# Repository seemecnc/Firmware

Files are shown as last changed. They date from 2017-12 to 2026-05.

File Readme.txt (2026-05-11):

Readme for SeeMeCNC 'firmware' repository 

May 2026 ~PartDaddy~

> Newest RepRapFirmware 3.6.2+1 for SeeMeCNC Deltas

> Specifically made for SeeMeCNC May 2026 release of Orca Slicer 2.3.2 SeeMeCNC factory profiles
> Duet3d RepRapFirmware 3.7.x will no longer support Duet2 control boards
> SeeMeCNC may provide further 3.6.x updates if needed

visit seemecnc.com menu item SUPPORT for technical help

All licenses in this repository are provided under the original authors' license, Duet3d, Ltd., Ultimachine, and others. 

SeeMeCNC makes no warranty for the use of this software and firmware. All software and firmware is provided "AS-IS" use at own risk. Please read 
licenses provided by other companies for their publication of software or firmware.

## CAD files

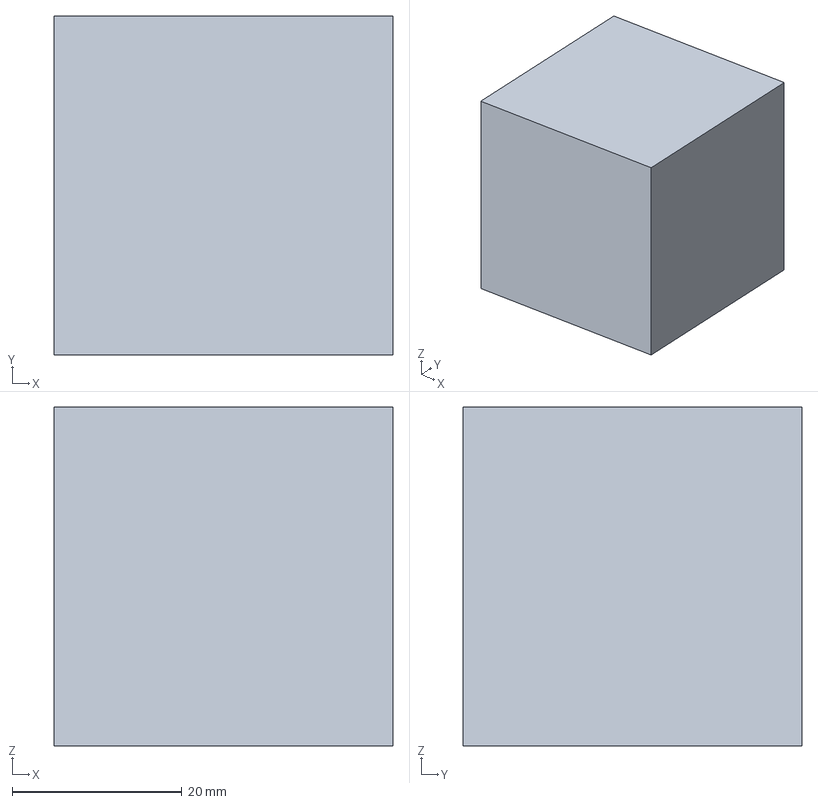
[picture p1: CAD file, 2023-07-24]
RepRapFirmware/ARTEMIS/gcodes/factory/40mmcubeCura462.3mf
40.0 x 40.0 x 40.0 mm

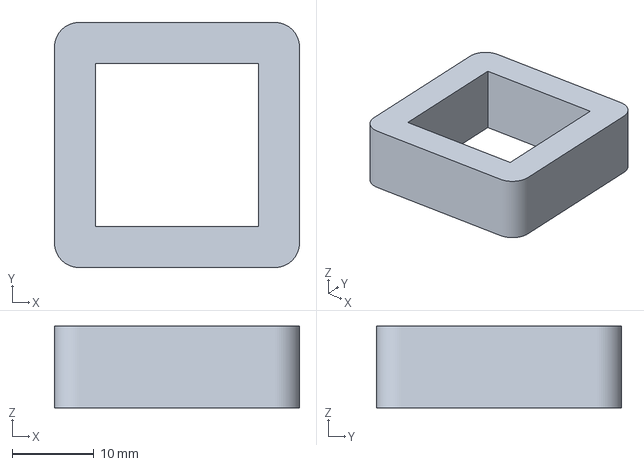
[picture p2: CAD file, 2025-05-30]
RepRapFirmware/BOSS 500/gcodes/factory/070noz/Calibration Square 30mm 07noz BOSS500 0521 Cura462.3mf
30.0 x 30.0 x 10.0 mm

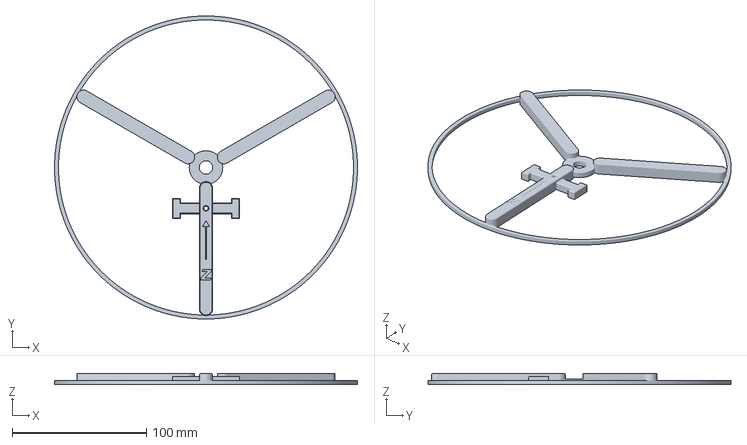
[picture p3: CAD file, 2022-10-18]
RepRapFirmware/V4/gcodes/factory/Calibration 100mm SMC Deltas.3mf
226.0 x 226.0 x 8.00 mm

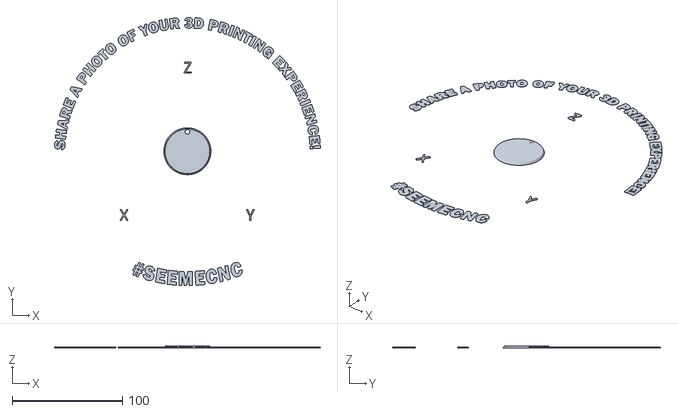
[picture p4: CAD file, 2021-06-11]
RepRapFirmware/ARTEMIS/gcodes/factory/SeeMeCNC Testing Wheel v4 DUAL Part B.stl
241.8 x 244.0 x 2.00

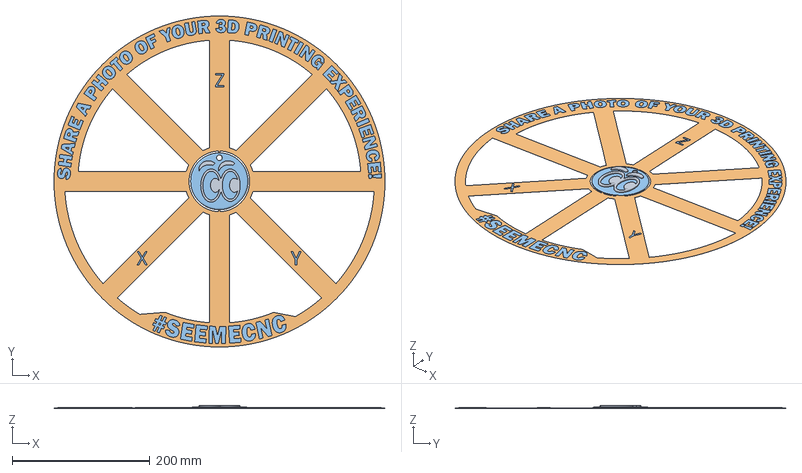
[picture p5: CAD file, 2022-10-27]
RepRapFirmware/BOSS 500/gcodes/factory/070noz/SeeMeCNC Testing Wheel BOSS 500 070noz.3mf
480.0 x 480.0 x 4.40 mm
SeeMeCNC Testing Wheel v4 DUAL Part C.stl
SeeMeCNC Testing Wheel v4 DUAL Part A.stl
SeeMeCNC Testing Wheel v4 DUAL Part B.stl

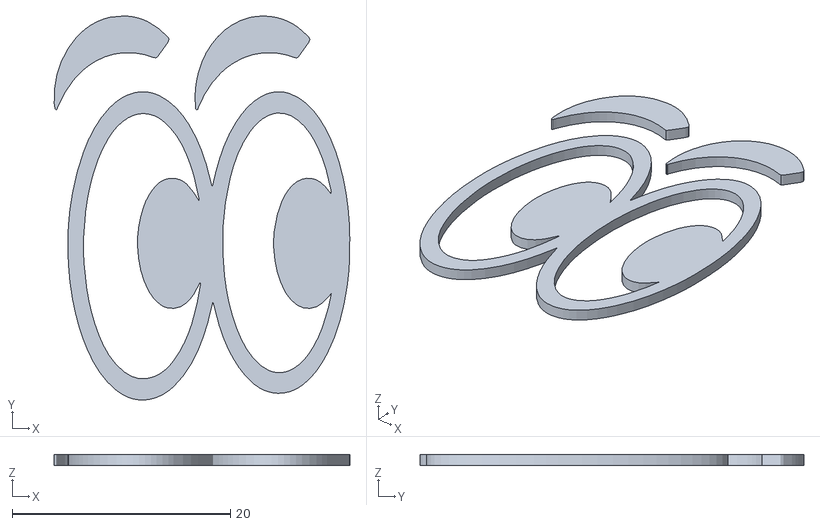
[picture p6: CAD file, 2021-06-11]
RepRapFirmware/ARTEMIS/gcodes/factory/SeeMeCNC Testing Wheel v4 DUAL Part C.stl
27.1 x 35.2 x 1.00

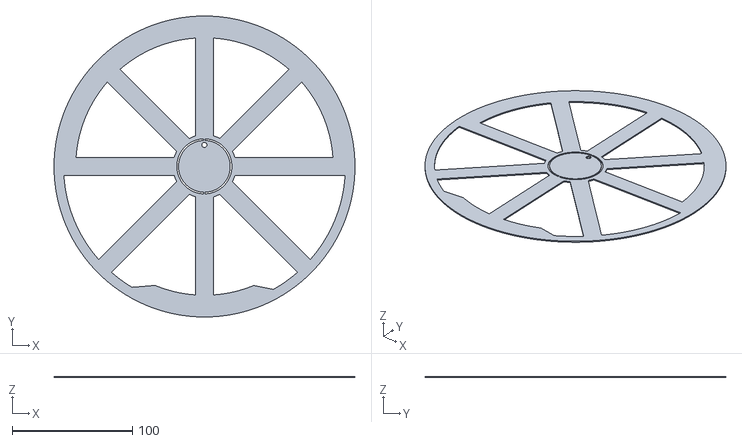
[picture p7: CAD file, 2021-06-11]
RepRapFirmware/V4/gcodes/factory/SeeMeCNC Testing Wheel v4 DUAL Part A.stl
250.0 x 250.0 x 1.00

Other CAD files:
RepRapFirmware/BOSS 300/gcodes/factory/40mmcubeCura462.3mf
RepRapFirmware/BOSS 300/gcodes/factory/Calibration 100mm SMC Deltas.3mf
RepRapFirmware/BOSS 300/gcodes/factory/Calibration 100mm SMC Deltas.STL
RepRapFirmware/Machine Configuration Files/archived machine configs/v3.2.2 Firmware END USE MAY 2023/BOSS 300/gcodes/factory/40mmcubeCura462.3mf
RepRapFirmware/Machine Configuration Files/archived machine configs/v3.2.2 Firmware END USE MAY 2023/BOSS 300/gcodes/factory/Calibration 100mm SMC Deltas.3mf
RepRapFirmware/Machine Configuration Files/archived machine configs/v3.2.2 Firmware END USE MAY 2023/BOSS 300/gcodes/factory/Calibration 100mm SMC Deltas.STL
RepRapFirmware/Machine Configuration Files/archived machine configs/v3.2.2 Firmware END USE MAY 2023/Boss 300 SD Card WiFi RRF322 eSlide/gcodes/factory/Calibration 100mm SMC Deltas.STL
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

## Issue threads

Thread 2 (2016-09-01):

Extruder Motor bug

junot566, 2016-09-01:
Hello guys

I was testing the new version REPETIER_VERSION "0.92.2" FIRMWARE_DATE "083116" and I think there is a bug with the extruder motor, for some reason with this version does not work, I have the Kysan or Automation Technology stepper motors and X, Y, Z are working great but E1 does not move at all.

As soon as I load the previous version back, everything works as normal, I tried this 2 times and I´´m getting the same problem.

btw, I did the current changes for the Kysan motors. MOTOR_CURRENT {175,175,175,200,0}.
Same problem

As far as I can see there are great features included on this version, really nice work.

regards

Adrian

johnoly99, 2016-09-08:
Hmm, @junot566 you say E1, but the default extruder motor for a single extruder is E0.  Double check that, as we are using this firmware exclusively and it's working for us here at the shoP?

Closed 2016-09-08.

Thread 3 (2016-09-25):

Retore Wantai Motor Comment in configuration.h

loadedsith, 2016-09-25:
https://github.com/seemecnc/Repetier-091-ROSTOCKMAX/blob/master/Repetier-091-ROSTOCKMAX/Repetier/Configuration.h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

Says:
     #define MOTOR_CURRENT {140,140,140,130,0} // Values 0-255 (RAMBO 135 = ~0.75A, 185 = ~1A)  use 140 for xyz and 130 for the E if using Kysan motors and 175 xyz and 200 if using wantai motors

Where the new version just says

    #define MOTOR_CURRENT {140,140,140,130,0} // Values 0-255 (RAMBO 135 = ~0.75A, 185 = ~1A)

The extra tip here was very helpful after my new hot end firmware update started giving me issues in the extruder motor, could we restore this comment, and possibly add a reminder to the firmware updating docs?

With lots of love!
-g-

loadedsith, 2016-09-26:
is dupe of #4

johnoly99, 2016-10-12:
Good point loadedsith,

Added comment back into configuration.h for motor current defs.  See commit #4

Closed 2016-10-12.

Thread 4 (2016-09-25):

Retore Wantai Motor Comment in configuration.h

loadedsith, 2016-09-25:
My new hotend upgrade had me stumped when the extruder motor started slipping. Eventually I remembered there was a motor change, and that led me to this line in the old firmware.

https://github.com/seemecnc/Repetier-091-ROSTOCKMAX/blob/master/Repetier-091-ROSTOCKMAX/Repetier/Configuration.h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

Line 701 of the old configuration.h says (be sure to scroll, this is very long line):

    #define MOTOR_CURRENT {140,140,140,130,0} // Values 0-255 (RAMBO 135 = ~0.75A, 185 = ~1A)  use 140 for xyz and 130 for the E if using Kysan motors and 175 xyz and 200 if using wantai motors

Where the new version just says:

    #define MOTOR_CURRENT {140,140,140,130,0} // Values 0-255 (RAMBO 135 = ~0.75A, 185 = ~1A)

The extra tip here was very helpful after my new hot end firmware update started giving me issues in the extruder motor, could we restore this comment, and possibly add a reminder to the firmware updating docs?

With lots of love!
-g-

johnoly99, 2016-10-12:
Good point loadedsith,

Added comment back into configuration.h for motor current defs.  See commit #3

loadedsith, 2016-10-12:
😄

Closed 2016-10-12.

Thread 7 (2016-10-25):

Intermittent Probing Issue

jjjohnson4112, 2016-10-25:
Reports of probing via the LCD is not functioning correctly. Probing using the GCODE file works fine.

Issues is not exactly repeatable every time, some times the machine will home and freeze. Other times the machine will home, drop down within Xmm of the bed and freeze.

Please find and fix bug.

johnoly99, 2016-11-24:
Fixed in dev branch as of 11/23, will be pushed to master on monday if no reports of other issues

Closed 2016-11-24.

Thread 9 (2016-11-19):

Auto-leveling is still not working right in the dev branch.

wwendorf, 2016-11-19:
Basically, I'm getting adhesion on the right side of the printer (from x0), but on the left side, no dice.

I posted some information in the forum on the bed leveling issue, some numbers and results that I have gotten from testing.

Would really like to get this fixed so I can get some printing done.

DerStig, 2016-11-22:
I am having the same problems nothing 20mm from the center will adhere on the X tower side. Prints are also very smashed between the y and Z towers.  End stops are adjusted all to read 0 or 1

While I can print a Benchy VERY well, I can't print anything bigger

wwendorf, 2016-11-22:
I'm having the same problem.  Contacted seemecnc support today, and they wanted me to print this file (http://repables.com/r/800/) and do an eeprom export using matter control, and open a ticket.

I have done that, as well as provided a video showing the problems with the calibration print.

johnoly99, 2016-11-24:
There's been a lot of commits to the dev branch in the past few days.  Testing at the shop has shown much better results.  Re-pull and try it now

Closed 2016-11-24.

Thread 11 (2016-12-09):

INVERT_Y_DIR not declared in HAL.h

axlspinedoc, 2016-12-09:
The following error comes up when I try to upload the firmware into a Rostock V2.
The only changes I made were in the Configuration.h tab where I declare that the printer is a Rostock V2.

Arduino: 1.6.13 (Windows 10), Board: "Arduino/Genuino Mega or Mega 2560, ATmega2560 (Mega 2560)"

In file included from sketch\HAL.h:77:0,

                 from sketch\Repetier.h:353,

                 from sketch\Commands.cpp:22:

sketch\Printer.h: In static member function 'static void Printer::setYDirection(bool)':

Printer.h:394: error: 'INVERT_Y_DIR' was not declared in this scope

             WRITE(Y_DIR_PIN,!INVERT_Y_DIR);

                              ^

sketch\fastio.h:29:35: note: in definition of macro '_WRITE'

 #define  _WRITE(IO, v)   do { if (v) {DIO ##  IO ## _WPORT |= MASK(DIO ## IO ## _PIN); } else {DIO ##  IO ## _WPORT &= ~MASK(DIO ## IO ## _PIN); }; } while (0)

                                   ^

sketch\Printer.h:394:13: note: in expansion of macro 'WRITE'

             WRITE(Y_DIR_PIN,!INVERT_Y_DIR);

             ^

Printer.h:401: error: 'INVERT_Y_DIR' was not declared in this scope

             WRITE(Y_DIR_PIN,INVERT_Y_DIR);

                             ^

sketch\fastio.h:29:35: note: in definition of macro '_WRITE'

 #define  _WRITE(IO, v)   do { if (v) {DIO ##  IO ## _WPORT |= MASK(DIO ## IO ## _PIN); } else {DIO ##  IO ## _WPORT &= ~MASK(DIO ## IO ## _PIN); }; } while (0)

                                   ^

sketch\Printer.h:401:13: note: in expansion of macro 'WRITE'

             WRITE(Y_DIR_PIN,INVERT_Y_DIR);

             ^

In file included from sketch\Repetier.h:486:0,

                 from sketch\Commands.cpp:22:

sketch\Printer.h: In static member function 'static bool Printer::getYDirection()':

Printer.h:430: error: 'INVERT_Y_DIR' was not declared in this scope

         return((READ(Y_DIR_PIN)!=0) ^ INVERT_Y_DIR);

                                       ^

exit status 1
'INVERT_Y_DIR' was not declared in this scope

This report would have more information with
"Show verbose output during compilation"
option enabled in File -> Preferences.

johnoly99, 2016-12-09:
Ahh, good catch!   Issue is fixed in commit 4ab60c0    The #DEFINE was missing for a v2, but it's there now

Closed 2016-12-09.

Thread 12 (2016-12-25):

Wantai/Kysan motor distinction still isn't commented in the firmware

gabegreenwood, 2016-12-25:
This issue is marked as closed:
https://github.com/seemecnc/Firmware/issues/4

But the comment doesn't actually seem to have made it into the firmware. I recently upgraded an old Rostock MAX v1 to what is now effectively a v3, which is great, but ittook me a while to figure out why my extruders were skipping - would have saved me some time if the comment had been sitting there in the firmware where I would have seen it right off the bat. Maybe look into if the commit got lost somewhere along the way?

brbubba, 2017-04-13:
Can confirm, here is the original comment:

// ################## RAMBo Digipot Motor current control settings ################
// Values 0-255 (RAMBO 135 = ~0.75A, 185 = ~1A)
// use 140 for xyz and 130 for the E if using Kysan/AutomationTechnology motors and 175 xyz and 200 if using wantai motors

I have an 11/14/16 build and a 12/09/16 build and the comment vanished somewhere between there. This seems like crucial info, especially now that I'm running BOTH Kysan (Extruder) and Wantai (Arms) motors.

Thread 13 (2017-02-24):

G28 X0 extrudes filament after G92 E0

AlanKilian, 2017-02-24:
If the extruder is zereod before performing an axis zero on a non-Z axis, the extruder runs because the  Printer::destinationSteps[E_AXIS] value does not get set to zero prior to the move.

g0 x0 y0 z100
g1 x100 e30 f2000 ; Make a move and extrude
g92 e0 ; zero the extruder
g28 x0 ; Move to X=0 and home

This sequence causes the extruder to extrude 30mm of filament during the move to x=0

AlanKilian, 2017-02-24:
Fix is as follows:

diff --git a/Repetier Firmware/Repetier/Printer.cpp b/Repetier Firmware/Repetier/Printer.cpp
old mode 100644
new mode 100755
index 53e413c..19bced0
--- a/Repetier Firmware/Repetier/Printer.cpp
+++ b/Repetier Firmware/Repetier/Printer.cpp
@@ -1034,6 +1034,10 @@ void Printer::homeAxis(bool xaxis,bool yaxis,bool zaxis) // Delta homing code
     // gratuitously fail due to incorrect settings.
     // The following movements would be meaningless unless it was zeroed for example.
     UI_STATUS_UPD(UI_TEXT_HOME_DELTA);
+
+    // For all homing operations, set the extruder target position to zero to avoid extruder operation
+    Printer::destinationSteps[E_AXIS] = 0;
+
     // Homing Z axis means that you must home X and Y
     if (homeallaxis || zaxis)
     {

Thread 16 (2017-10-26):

Random Tool Change (2 into 1 add-on)

HippoDan, 2017-10-26:
Printing from Octoprint frequently finds an extruder switch at random, uncommanded.  The forum also reports this problem on any USB connection, not just Octoprint.  I'm currently testing this from the SD card, which does not seem to have the same problem.

teejaydub, 2017-12-06:
It seems like printing from the SD card is a decent workaround for that problem if printing from the SD card fits with your workflow. It doesn't for me, so, working on Ryan's assessment that the problem is caused by too much RAM being used by the second extruder, I tried disabling SD card support instead:

https://github.com/teejaydub/Firmware/commit/cea255d91da2b6eb7f2232bd476d6cb9317e3c6a

(of course you also need to set `NUM_EXTRUDER` to 2, but I wanted to leave my repo ready for a pull request)

That frees up quite a bit of RAM - it goes down from 89% usage with one extruder + SD card support to 81% with two extruders + no SD card support.

Time will tell if this fixes the random extruder switches, but I got through one print OK and will report back as I get more experience with it.

louvanna, 2018-01-18:
Using cea255d firmware on RostockMax V3 -dual, and have the same RAM %'s using IDE Arduino 1.8.4.    I am 0 for 2 attempts where the controller will stall early into a print and eventually go into reset. No joy.
There is one other comment elsewhere about memory overflow  "Array memory overrun fix and ui_lang.h inclusion fix. [#14](https://github.com/seemecnc/Firmware/pull/14/commits/02ca6c6eb7fbb94d15bb4ef9699078905145242e)"  , but have yet to incorporate that yet.

teejaydub, 2018-01-18:
Hm, stalling and resetting could be a different problem? I haven't seen that at all.

louvanna, 2018-01-19:
I am using OctoPrint as the USB controller. Clarification, the LCD initially shows Extruder0 , as intended. The delta stalls after the LCD changes to Extruder1, but the extruder stepper (1) is now active. So really the delta has stalled, but the firmware is still executing something.

dbfrompw, 2018-01-21:
On the Rostock V2, if set to 2 extruders, if you change to 2nd extruder, it locks up and needs rebooting.  V91 works but cant get inductive probe to work.

louvanna, 2018-01-23:
A rollback to v2 / v91, would mean forgoing the HE280 accelerometer, nope.
Update,  it works somewhat.
After deep thought, in the fog the 2017/2018 seasonal flu, I forgot to erase the EEProm prior to the new upload, and recalib.
Remedying this omission, I can now print for an hour+ before a random tool change away from T0. Too bad my print is 7 hrs. While it printed with an empty T1, I manually simply moved my filament spool from T0 to T1. Many layers and hours later, the printer was found cold/idle, with its head buried at the print surface, and the LCD display line, 'Print Killed'.

Machine: dual 'Y" extruder kit, Rostock Max v3, firmware  cea255d plus pull #14,
Controller: OctoPrint 1.3.6 as the USB controller on RPI.

EliW, 2019-02-21:
Chiming in here:  There is an identical/similar bug being discussed over on the OctoPrint Github (because I filed it a while back not knowing about this one):
https://github.com/foosel/OctoPrint/issues/3031

Basically I'm having this exact same issue.  However, with a couple twists:

- I'd been printing fine for months with a dual extruder over USB, when connected to a desktop and S3D.   I only started to have this random extruder-swap when moving to using OctoPi
- I've recently had a different fault while debugging the extruder swap.  Where some garbled communication caused an issue 15hrs into a 16hr print (after I'd originally found a workaround of 'print only on T1' which got me past the 1hr point.   But it seems, only to a 15hr point.

HippoDan, 2019-02-21:
I found s solution for this a while back.  Cut the data rate in half. Simply reducing the baud rate in octoprint to 115000 or whatever it is, made the problem go away entirely.  It would take a lot longer to transfer files to the sd card through octoprint, but I never do that, and print speed is unaffected.

EliW, 2019-02-26:
So:  New problems from this weekend (and this morning)

I've been printing 24/7 in preparation for an event.   And twice now I've had extruder changes **while printing from an SD card**.  The latest one this morning.

So now I'm completely flummoxed as to what to do.    I did still have Octoprint connected via USB.  But just hanging out monitoring.  So if just 'being connected' is enough to trigger the bug ... *OR* ... It has nothing to do with Octoprint at all.

I'm seriously considering just reflashing my firmware to single extrusion and considering the whole dual extrusion addon to be complete junk because of this :(

And I was really looking forward to making more dual extrusion awesomeness....

teejaydub, 2019-02-26:
I haven't been looking into this much, because I have had persistent stringing problems, making dual extrusion spectacularly crappy even without random tool changes. BUT I just wanted to put this out there: it smells a lot like a buffer overflow I recently found in a totally different project. I would like to get some time to investigate what happens when the firmware runs out of RAM for incoming data - in particular, does something get overwritten, by a class C array overrun or some other way?

Just in case someone else has the time to pursue that angle before I do.

I'm not sure how that would explain the issue when printing from SD.

EliW, 2019-02-27:
I dunno, buffer flow sounds like a legit issue here (and why I prefer coding in higher level languages now-a-days) ... Even on SD card, just perhaps for different reasons.

If you look in the other thread at my output, you'll see in one case where the Rostock sent a very garbled message, which totally looks like a buffer overflow situation (or at least a non-cleared buffer).   So that's not a bad theory.

while USB is attached, and connected, it's still constantly communicating with the Octoprint, sending the 'SD printin byte' commands, and temperature reports at times.

I will also add, that the models that this started happening to me on, also happen to be very complicated models.  IE:  When I was printing single extrusion AFTER upgraded to the Y and it was working, it was over USB via S3D ... and I had zero issues.

But those, while sometimes LARGE prints (12"x12"x12") ... were very simple prints.   Lots of straight lines, box shapes, etc.   So the GCODE was actually very small.

When I started seeing hte problems was not just when I switched to Octoprint, but also I started printing wargaming terrain for an upcoming con that I'm running.   And now these was things like 'stone walls' where there isn't a single flat surface.   Looking at the Gcode, it's HUGE, as it's a constant mess of "go 0.1mm this direction, now 0.1mm that direction, now 0.1mm that directino' ... to get the 'rippling' effect of stone.

Also FWIW:  The two I've had that switched while printing on the SD card.  Both did it at an obvious point of 'change' in the model.  That may just be coincidence.   But basically one was between two layers of brick perfectly.   The other was right before a line of skull/wings happened, again, perfectly.   May just be coincidence.
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
EliW, 2019-11-11:
Been looking at the code.  It does seem that 'something' is happening in your code, on my machine, that is causing your line 350 in gcode.cpp to fire constantly, for almost every line.

As if the buffer was constantly full.

  (Alternatively, something is triggering one of the lower requestResend()'s in the main code.)

A couple things I noticed, that may or may not be related:

1) It seems like memory is very tight.  Your version compiled (with SD card support) gives a warning that only 744 bytes are available for local vars on the Arduino.  The regular version says 745 (oooh, 1 byte!).   I assume that this is why you had been disabling the SD card support.   Compiling without SD Card support opens it up to 1519 bytes of memory.  (I have not tested your code running without that, partially because right now I'm waiting for the print on the original to finish that I started.  And partially because I'd hate to completely lose SD card as an option.   Also, 1 byte really (really) shouldn't be a huge issue.

2) Looking at the code (I admit my cpp is rusty, very) ... I'm not sure I grok how the resend works.  It appears that when you call the requestResend() as you do, it just says "What was the last line number I ran. Oh right, X ... Ask for X+1 to be sent to me."    It doesn't appear to have a "But what was the last number I was sent, and request up to that number?    Since the resend only sends that one line.   I guess there is code in there (line 195) that perhaps keeps sending them.  IE:  If the last you ran was 100, but the connection is trying to send you 105.   That line would go 'nope', and it would request 101 ... then (I assume, somehow) it would go back to seeing that 105 was sent to it.  And go nope: 102 please.   But again, can't quite grok the code to ensure that's exactly what it's trying to do there.   Seems a bit weird that it would fall back to this odd loop, instead of having a section that goes "Oh hey, the printer sent me 105, but I need 101, 102, 103, 104, let's ask for those in sequence?

Anyway, looking forward to hearing back.    Also, I'm wondering if the un-merged buffer overlow bug here as a pull request might be having anything to do with these issues...

teejaydub, 2019-11-12:
Yes, that behavior doesn't surprise me. The dual-extruder code requires a duplicate of the whole structure for the second extruder, which might make it just run out of heap space at run time (they are dynamically allocated, if I remember correctly).

So yeah - I didn't try to get it to work with the SD card support, but I doubt you can do dual and SD on this machine. Just not enough memory on the microcontroller. :(

I believe I merged the un-merged buffer overflow bug into my patch, so that shouldn't be an issue.

I wonder if reducing the connection baud rate would help diagnose or otherwise provide useful info?

EliW, 2019-11-13:
But literally upon compiling, it's a 1 byte difference between your code and the base code.   Because all you are doing is keep an extra flag.  Then deciding to stop reading from the port when full, and requesting a resend when done.

I can test it without the SD card code in it.

I'm also tempted to debug it some by putting in some responses across the USB to see which code is triggering the resend.

teejaydub, 2019-11-13:
> But literally upon compiling, it's a 1 byte difference between your code and the base code. Because all you are doing is keep an extra flag. Then deciding to stop reading from the port when full, and requesting a resend when done.

Yes, that's true about my additional code. I meant the dual-extruder mode - I was never able to get that to compile and run with SD card support at the same time. But there's plenty of options for failure, so it might have been something else going wrong when I tried that!

> I can test it without the SD card code in it.

It would at least be an interesting diagnostic, even if you really want the SD support.

> I'm also tempted to debug it some by putting in some responses across the USB to see which code is triggering the resend.

That might be interesting too.  One other thing to consider is whether your USB cable is flaky... I'm just trying to think of what else could cause that many transmission errors. Lowering baud rate too.

EliW, 2019-11-14:
> Yes, that's true about my additional code. I meant the dual-extruder mode

Sure, but the dual-extruder mode works perfectly fine (other than the random tool changes & restarts if connected to USB).   The fact that adding your '1 byte of code', suddenly made it make constant requests for resends.  Seems 'odd'/'buggy' there.

> (without SD code)

Yeah, hopefully tonight (EDT here) I'm going to sit down
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

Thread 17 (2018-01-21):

Can't make "Reprap Discount Full Graphic Display" 12864 work.

dbfrompw, 2018-01-21:
Changed the configuration.h to 11 and nothing. Please fix

PartDaddy, 2021-08-24:
Factory printers only used 4 line display controllers. Other aftermarket types, such as the graphics controllers, are not tested by factory.

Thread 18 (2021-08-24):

V2 invert issue

Slashthedragon, 2021-08-24:
After uploading to my Rostock Max V2 the axes were not driving in the correct direction.
I edited the setting for directions in the V2 settings and now it drives in the correct direction. I still can't get it level but I am getting closer. As noted elsewhere, you will need to set the Configuration.h for V2 printer and use Arduino 1.0.6

#define INVERT_X_DIR 0 // was 1
#define INVERT_Y_DIR 0
#define INVERT_Z_DIR 0 // was 1

PartDaddy, 2021-08-24:
Hi Slashthedragon,
1. No need to change firmware unless you really want to.
The official factory response for steppers moving the wrong direction is to turn the plug around at the RAMBo. This reverses the stepper direction without the need to modify firmware.
2. Arduino 1.6.0

Closed 2021-08-24.

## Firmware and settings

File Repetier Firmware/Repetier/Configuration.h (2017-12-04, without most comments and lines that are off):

#define PRINTER 5
#define HOTEND 3
#define MOTHERBOARD 301
#define POWER_SUPPLY 2
#define NUM_EXTRUDER 1
#define REPETIER_VERSION "0.92.2"
#define FIRMWARE_DATE "20171204" // in date format yyyymmdd
#define CONFIGURATION_H
#define ADVANCED_USER 1 // Change to 1 to unlock full menus
#include "pins.h"
#define MICROSTEP_MODES {16,16,16,16,16} // 1,2,4,8,16
#if MOTHERBOARD == 301  // RAMBo
#define STEPPER_CURRENT_CONTROL CURRENT_CONTROL_DIGIPOT
#elif MOTHERBOARD == 302  // Mini RAMBo
#define STEPPER_CURRENT_CONTROL CURRENT_CONTROL_PWM
#define MOTOR_CURRENT_PWM_RANGE 2000
#endif
#define Z_LIFT_ON_PAUSE 20         // Amount to lift the head (mm) when pausing from the LCD screen
#define MIN_DEFECT_TEMPERATURE 16  // this is the min temp that will allow the hotend to start heating.  Below this it will show as defective to help identify bad thermistors
#define MAX_DEFECT_TEMPERATURE 300 // this is the max temp that wthe printer will throw errors about defective thermistors
#define MIXING_EXTRUDER 0
#define DRIVE_SYSTEM 3
#define BELT_PITCH 2
#define PULLEY_TEETH 20
#define PULLEY_CIRCUMFERENCE (BELT_PITCH * PULLEY_TEETH)
#define PULLEY_DIAMETER 10
#define STEPS_PER_ROTATION 200
#define MICRO_STEPS 16
#define AXIS_STEPS_PER_MM ((float)(MICRO_STEPS * STEPS_PER_ROTATION) / PULLEY_CIRCUMFERENCE)  // for deltas with 1.8 deg. steppers and 20 tooth GT2 pulleys
#define XAXIS_STEPS_PER_MM AXIS_STEPS_PER_MM
#define YAXIS_STEPS_PER_MM AXIS_STEPS_PER_MM
#define ZAXIS_STEPS_PER_MM AXIS_STEPS_PER_MM
#define MIN_EXTRUDER_TEMP 150
#if HOTEND == 1
#define MAXTEMP 240
#define UI_SET_MAX_EXTRUDER_TEMP 240
#define EXT0_PID_INTEGRAL_DRIVE_MAX 180
#define EXT0_PID_INTEGRAL_DRIVE_MIN 80
#define EXT0_PID_PGAIN_OR_DEAD_TIME 14.50
#define EXT0_PID_I 0.73
#define EXT0_PID_D 53.41
#define EXT0_PID_MAX 235
#define EXT1_PID_INTEGRAL_DRIVE_MAX 180
#define EXT1_PID_INTEGRAL_DRIVE_MIN 80
#define EXT1_PID_PGAIN_OR_DEAD_TIME 14.50
#define EXT1_PID_I 0.73
#define EXT1_PID_D 53.41
#define EXT1_PID_MAX 235
#elif HOTEND == 2
#define MAXTEMP 240
#define UI_SET_MAX_EXTRUDER_TEMP 240
#define EXT0_PID_INTEGRAL_DRIVE_MAX 200
#define EXT0_PID_INTEGRAL_DRIVE_MIN 120
#define EXT0_PID_PGAIN_OR_DEAD_TIME 25.0
#define EXT0_PID_I 0.85
#define EXT0_PID_D 176.0
#define EXT0_PID_MAX 210
#elif HOTEND == 3
#define MAXTEMP 290
#define UI_SET_MAX_EXTRUDER_TEMP 280
#define EXT0_PID_INTEGRAL_DRIVE_MAX 230
#define EXT0_PID_INTEGRAL_DRIVE_MIN 80
#define EXT0_PID_PGAIN_OR_DEAD_TIME 48.3
#define EXT0_PID_I 9.7
#define EXT0_PID_D 60.0
#define EXT0_PID_MAX 255
#define EXT1_PID_INTEGRAL_DRIVE_MAX 230
#define EXT1_PID_INTEGRAL_DRIVE_MIN 80
#define EXT1_PID_PGAIN_OR_DEAD_TIME 48.3
#define EXT1_PID_I 9.7
#define EXT1_PID_D 60.0
#define EXT1_PID_MAX 255
#endif
#define PDM_FOR_EXTRUDER 0
#define PDM_FOR_COOLER 0
#define FEATURE_WATCHDOG 1
#define DECOUPLING_TEST_MAX_HOLD_VARIANCE 20
#define DECOUPLING_TEST_MIN_TEMP_RISE 1
#define RETRACT_ON_PAUSE 2
#define PAUSE_START_COMMANDS "G91/nG1 Z10.0 E-5.0 F1500/nG90/n"
#define PAUSE_END_COMMANDS "G91/nG1 Z-10.0 E5.1 F1500/nG90/n"
#define EXT0_X_OFFSET 0
#define EXT0_Y_OFFSET 0
#define EXT0_STEPS_PER_MM 92.4
#define EXT0_TEMPSENSOR_TYPE 97 //97
#define EXT0_TEMPSENSOR_PIN TEMP_0_PIN
#define EXT0_HEATER_PIN HEATER_0_PIN
#define EXT0_STEP_PIN ORIG_E0_STEP_PIN
#define EXT0_DIR_PIN ORIG_E0_DIR_PIN
#define EXT0_INVERSE 1
#define EXT0_ENABLE_PIN E0_ENABLE_PIN
#define EXT0_ENABLE_ON 0
#define EXT0_MAX_FEEDRATE 100
#define EXT0_MAX_START_FEEDRATE 45
#define EXT0_MAX_ACCELERATION 6500
#define EXT0_HEAT_MANAGER 1
#define EXT0_WATCHPERIOD 3
#define EXT0_ADVANCE_K 0
#define EXT0_ADVANCE_L 0
#define EXT0_ADVANCE_BACKLASH_STEPS 0
#define EXT0_WAIT_RETRACT_TEMP 150
#define EXT0_WAIT_RETRACT_UNITS 0
#define EXT0_SELECT_COMMANDS "M117 Extruder 0\nT0\nM84 P4\nG91\nG1E172F6000\nG1E5F500\nG90"
#define EXT0_DESELECT_COMMANDS "G91\nG1E-180F6000\nG90"
#if MOTHERBOARD == 301
#define EXT0_EXTRUDER_COOLER_PIN 7
#elif MOTHERBOARD == 302
#define EXT0_EXTRUDER_COOLER_PIN -1
#endif
#define EXTRUDER_FAN_COOL_TEMP 40
#define EXT0_EXTRUDER_COOLER_SPEED 200
#define EXT0_DECOUPLE_TEST_PERIOD 45000
#define EXT1_X_OFFSET 0
#define EXT1_Y_OFFSET 0
#define EXT1_STEPS_PER_MM 92.4
#define EXT1_TEMPSENSOR_TYPE 97 //97
#define EXT1_TEMPSENSOR_PIN TEMP_1_PIN
#define EXT1_HEATER_PIN HEATER_1_PIN
#define EXT1_STEP_PIN ORIG_E1_STEP_PIN
#define EXT1_DIR_PIN ORIG_E1_DIR_PIN
#define EXT1_INVERSE 1
#define EXT1_ENABLE_PIN E1_ENABLE_PIN
#define EXT1_ENABLE_ON 0
#define EXT1_MAX_FEEDRATE 100
#define EXT1_MAX_START_FEEDRATE 45
#define EXT1_MAX_ACCELERATION 6500
#define EXT1_HEAT_MANAGER 1
#define EXT1_WATCHPERIOD 3
#define EXT1_ADVANCE_K 0
#define EXT1_ADVANCE_L 0
#define EXT1_ADVANCE_BACKLASH_STEPS 0
#define EXT1_WAIT_RETRACT_TEMP 150
#define EXT1_WAIT_RETRACT_UNITS 0
#define EXT1_SELECT_COMMANDS "M117 Extruder 1\nT1\nM84 P4\nG91\nG1E172F6000\nG1E5F500\nG90"
#define EXT1_DESELECT_COMMANDS "G91\nG1E-180F6000\nG90"
#if MOTHERBOARD == 301
#define EXT1_EXTRUDER_COOLER_PIN 7
#elif MOTHERBOARD == 302
#define EXT1_EXTRUDER_COOLER_PIN -1
#endif
#define EXTRUDER_FAN_COOL_TEMP 40
#define EXT1_EXTRUDER_COOLER_SPEED 200
#define EXT1_DECOUPLE_TEST_PERIOD 45000
#define HEATED_BED_MAX_TEMP 120
#define SKIP_M190_IF_WITHIN 5
#define HEATED_BED_SENSOR_TYPE 97 //97
#define HEATED_BED_SENSOR_PIN TEMP_BED_PIN
#define HEATED_BED_HEATER_PIN HEATER_BED_PIN
#define HEATED_BED_SET_INTERVAL 5000
#define HEATED_BED_HEAT_MANAGER 1
#define HEATED_BED_PID_INTEGRAL_DRIVE_MAX 255
#define HEATED_BED_PID_INTEGRAL_DRIVE_MIN 80
#define HEATED_BED_PID_PGAIN_OR_DEAD_TIME   87.86
#define HEATED_BED_PID_IGAIN   3.01
#define HEATED_BED_PID_DGAIN 641.82
#define HEATED_BED_PID_MAX 255
#define HEATED_BED_DECOUPLE_TEST_PERIOD 300000
#if PRINTER == 1  // Orion Delta
#if MOTHERBOARD == 301
#if NUM_EXTRUDER == 1
#define MOTOR_CURRENT {140,140,140,130,0}
#elif NUM_EXTRUDER == 2
#define MOTOR_CURRENT {140,140,140,145,145}
#endif
#elif MOTHERBOARD == 302
#define MOTOR_CURRENT_PWM {60, 60, 130}
#endif
#define HAVE_HEATED_BED 1
#define INVERT_X_DIR 1
#if POWER_SUPPLY == 2
#define INVERT_Y_DIR 1
#else
#define INVERT_Y_DIR 0
#endif
#define INVERT_Z_DIR 1
#define DELTA_DIAGONAL_ROD 178.0  // ball cup arms
#define DELTA_MAX_RADIUS 90.0
#define PRINTER_RADIUS 145.7
#define Z_MAX_LENGTH 230.0
#define END_EFFECTOR_HORIZONTAL_OFFSET 30.22
#define CARRIAGE_HORIZONTAL_OFFSET 26.5  // molded cheapskates
#define DELTASEGMENTS_PER_PRINTLINE 22
#define STEPPER_INACTIVE_TIME 600L
#define MAX_INACTIVE_TIME 900L
#define MAX_FEEDRATE_X 250
#define MAX_FEEDRATE_Y 250
#define MAX_FEEDRATE_Z 250
#define HOMING_FEEDRATE_X 80
#define HOMING_FEEDRATE_Y 80
#define HOMING_FEEDRATE_Z 80
#define MAX_ACCELERATION_UNITS_PER_SQ_SECOND_X 1650
#define MAX_ACCELERATION_UNITS_PER_SQ_SECOND_Y 1650
#define MAX_ACCELERATION_UNITS_PER_SQ_SECOND_Z 1650
#define MAX_TRAVEL_ACCELERATION_UNITS_PER_SQ_SECOND_X 2800
#define MAX_TRAVEL_ACCELERATION_UNITS_PER_SQ_SECOND_Y 2800
#define MAX_TRAVEL_ACCELERATION_UNITS_PER_SQ_SECOND_Z 2800
#define MAX_JERK 28
#define MAX_ZJERK 28
#if HOTEND == 3
#define FEATURE_Z_PROBE 1
#else
#define FEATURE_Z_PROBE 0
#endif
#define Z_PROBE_SENSITIVITY  20 // 0-126 7 bit value
#define Z_PROBE_BED_DISTANCE 20
#define Z_PROBE_PULLUP 1 //0
#define Z_PROBE_ON_HIGH 0 //1
#define Z_PROBE_X_OFFSET 0
#define Z_PROBE_Y_OFFSET 0
#define Z_PROBE_WAIT_BEFORE_TEST 0
#define Z_PROBE_SPEED 60
#define Z_PROBE_XY_SPEED 50
#define Z_PROBE_SWITCHING_DISTANCE 10
#define Z_PROBE_REPETITIONS 1
#define Z_PROBE_HEIGHT -0.1
#define Z_PROBE_START_SCRIPT "G28/nG1Z25/n"
#define Z_PROBE_FINISHED_SCRIPT ""
#define FEATURE_AUTOLEVEL 1
#define Z_PROBE_X1 -75.933
#define Z_PROBE_Y1 -43.84
#define Z_PROBE_X2 75.933
#define Z_PROBE_Y2 -43.84
#define Z_PROBE_X3 0
#define Z_PROBE_Y3 87.69
#define SDSUPPORT 1
#define SDCARDDETECT 81
#define SDCARDDETECTINVERTED 0
#define FEATURE_CONTROLLER 13
#define UI_PRINTER_NAME "ORION Delta"
#define SDSUPPORT 1
#define SDCARDDETECT 81
#define SDCARDDETECTINVERTED 0
#elif PRINTER == 2 // Rostock MAX v2
#if NUM_EXTRUDER == 1
#define MOTOR_CURRENT {140,140,140,130,0}
#elif NUM_EXTRUDER == 2
#define MOTOR_CURRENT {140,140,140,130,130}
#endif
#define HAVE_HEATED_BED 1
#define INVERT_X_DIR 1
#define INVERT_Y_DIR 0
#define INVERT_Z_DIR 1
#define DELTA_DIAGONAL_ROD 291.06  // ball cup arms
#define DELTA_MAX_RADIUS 145.0
#define PRINTER_RADIUS 200.0
#define Z_MAX_LENGTH 350
#define END_EFFECTOR_HORIZONTAL_OFFSET 30.22
#define CARRIAGE_HORIZONTAL_OFFSET 26.5  // molded cheapskates
#define DELTASEGMENTS_PER_PRINTLINE 22
#define STEPPER_INACTIVE_TIME 600L
#define MAX_INACTIVE_TIME 900L
#define MAX_FEEDRATE_X 250
#define MAX_FEEDRATE_Y 250
#define MAX_FEEDRATE_Z 250
#define HOMING_FEEDRATE_X 80
#define HOMING_FEEDRATE_Y 80
#define HOMING_FEEDRATE_Z 80
#define MAX_ACCELERATION_UNITS_PER_SQ_SECOND_X 1850
#define MAX_ACCELERATION_UNITS_PER_SQ_SECOND_Y 1850
#define MAX_ACCELERATION_UNITS_PER_SQ_SECOND_Z 1850
#define MAX_TRAVEL_ACCELERATION_UNITS_PER_SQ_SECOND_X 3000
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

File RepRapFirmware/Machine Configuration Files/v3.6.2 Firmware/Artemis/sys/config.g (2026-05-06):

; SeeMeCNC 3D Printer Config 
; MAY 2026 v3.6.2+1 Duet Firmware
; Optimized for SeeMeCNC factory Orca Slicer software
; ***important*** M92 Steps/mm on all axis extruders must be calibrated manually
;
; General Settings
G90                                 ; absolute coordinates
M83                                 ; relative extruder moves
M550 P"ARTEMIS"                     ; set printer name

; Set Global Variables
global T_bed_0    = 0               ; {material_bed_temperature_layer_0}
global T_tool_0   = 0               ; {material_print_temperature_layer_0}
global T_bed      = 0               ; {material_bed_temperature}
global T_tool     = 0               ; {material_print_temperature}
global bed_type = "Unknown"			; build plate type from Orca for mesh/offset saving
global filament_type = "Unknown"    ; filament type for offset saving

; User Set Global M665 Variables
global deltaRadius = 160            ; Horizontal radius (R) 160=CF arms and SMC carriages;  155=CF Arms and Linear Rails;  150=CF Arms and Linear Rails
global armLength = 340.5            ; Diagonal rod length (L) 340.5=CF Arms; 351.1=Injection Molded Arms
global bedRadius = 155              ; Printable bed radius (B) 155=CF Arms; 145=Injection Molded Arms
global homedHeight = 540            ; Homed height (H) 540=CF Arms; 530=Injection Molded Arms

M665 R{global.deltaRadius} L{global.armLength} B{global.bedRadius} H{global.homedHeight}  ; Delta Parameters
M666 X0 Y0 Z0 A0 B0                 ; endstop adjustment (this is set by autocalibration leveling)
M208 Z0 S1                          ; set Z axis minimum limit

; Network & Comms
;M540 PF0:E1:D2:C4:11:11	                             ; Ethernet Only -> set unique MAC Address for each SeeMeCNC printer
M586 P0 S1                                              ; Enable HTTP
G4 P500                                                 ; pause
M552 S1                                                 ; enable network and acquire dynamic address via DHCP
G4 P500                                                 ; pause
M586 P1 S0                                              ; disable FTP
M586 P2 S0                                              ; disable Telnet
M575 P1 S1 B57600                                       ; PanelDue Comm Setup

; Drive Parameters
M569 P0 S0                                              ; physical drive 0
M569 P1 S0                                              ; physical drive 1
M569 P2 S0                                              ; physical drive 2
M569 P3 S1                                              ; physical drive 3
M569 P4 S1                                              ; physical drive 4
M584 X0 Y1 Z2 E3:4                                      ; set drive mapping
M350 X16 Y16 Z16 E16:16 I1                              ; configure micro stepping with interpolation
M92 X200.00 Y200.00 Z200.00 E182.00:182.00              ; set steps per mm - ALL MUST BE CALIBRATED
M566 X1500.00 Y1500.00 Z1500.00 E1500.00:1500.00        ; set maximum instantaneous speed changes (mm/min) aka Jerk
M203 X12000.00 Y12000.00 Z12000.00 E9000.00:9000.00     ; set maximum speeds (mm/min)
M201 X2000.00 Y2000.00 Z2000.00 E3000.00:3000.00        ; set accelerations (mm/s^2)
M906 X1600 Y1600 Z1600 E1600:1600 I30                   ; set motor currents (mA) and motor idle factor in per cent
M84 S30                                                 ; Set motor idle timeout (seconds)

; End-stops
M574 X2 S1 P"xstop"                                     ; configure active-high endstop for high end on X via pin xstop
M574 Y2 S1 P"ystop"                                     ; configure active-high endstop for high end on Y via pin ystop
M574 Z2 S1 P"zstop"                                     ; configure active-high endstop for high end on Z via pin zstop

; Z-Probe
M558 P5 I0 A4 R0.4 C"zprobe.in" H20 F2500 T6000         ; HOTEND PROBEset Z probe type to switch and the dive height + speeds
G31 P500 X0 Y0 Z-0.4                                    ; set Z probe trigger value, offset and trigger height
M557 R130 S30                                           ; define mesh grid

; Bed Heater
M308 S0 P"bedtemp" Y"thermistor" A"Heated Bed" T100000 B4725 C7.06e-8 ; configure sensor 0 as thermistor on pin bed temp
M950 H0 C"bedheat" T0                                   ; create bed heater output on bed heat and map it to sensor 0
M307 H0 R0.125 K0.170:0.000 D35.00 E1.35 S1.00 B0       ; Bed Heater Process Parameters Tuning M303 H0 P1 S80
M140 H0                                                 ; map heated bed to heater 0
M143 H0 P0 T0 C0 S120 A0                                ; set temperature limit for heater 0 to 120C

; Hotend Heater
M308 S1 P"e0temp" Y"thermistor" A"Hotend" T100000 B4725 C7.06e-8  ; configure sensor 1 as thermistor on pin e0temp
M950 H1 C"e0heat" T1                                    ; create nozzle heater output on e0heat and map it to sensor 1
M307 H1 R3.500 K0.650:0.300 D8.00 E1.35 S1.00 B0 V13.0  ; Example Heater Tuning Command  M303 H1 P1 S250
M143 H1 S280                                            ; Hotend Max Temp

; Fans
M950 F0 C"fan0" Q500                                    ; create fan 0 on pin fan0 and set its frequency
M106 P0 S0 H-1                                          ; set fan 0 value. Thermostatic control is turned off
M950 F1 C"fan2" Q500                                    ; create fan 1 on pin fan1 and set its frequency
M106 P1 S0.80 H1 T45                                    ; set fan 1 value. Thermostatic control is turned on

; Tool Extruder 1
M563 P0 D0 H1 F0
G10 P0 X0 Y0 Z0
G10 P0 S0 R0

; Tool Extruder 2
M563 P1 D1 H1 F0
G10 P1 X0 Y0 Z0
G10 P1 S0 R0

; Input Shaping
; M593 P"ei3" F28 S0.1                                   ; not tuned but kept for future reference
; M593 P"mzv" F25 S0                                     ; not precisely tuned

;Filament Runout Sensor
M950 J0 C"!^e0Stop"                                     ; create switch pin
M950 J1 C"!^e1stop"                                     ; create switch pin
M581 P0:1 T2 S1 R1                                      ; run trigger2.g to pause if filament has run out during SD card printing

; Miscellaneous
M501                                                    ; load saved parameters from non-volatile memory
T0                                                      ; select Tool 0
M911 S11.0 R11.2 P"M913 X0 Y0 G91 M83 G1 Z3 E-5 F1000"  ; set voltage thresholds and actions to run on power loss

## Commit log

2016-06-08 Added Repetier Based Firmware Directory
    Added repetier firmware with universal configs for all printers
    [Configuration.h]
2016-06-08 migrated to repetier directory
    added folder for repetier firmware
    [Configuration.h]
2016-06-14 added droplit config defaults for firmware to compile
    added probe related configs for droplit with false/null values to get
    firmware to compile
    [Configuration.h]
2016-06-14 added notes to baudrate for droplit
    droplit uses 115200 baud for raspi compatibility, not 250000
    [Configuration.h]
2016-06-14 Splitting out motor current, enstop and speed settings AND fixed pins.h for pwm motor current on mini rambo
    Defined each printer models motor current settings, endstop settings and
    speed/accel settings AND fixed pins.h pwm motor current pins
    [Configuration.h]
2016-06-14 updated config for droplit and changed pins for motor current in pins
    rolled back pins.h change as they were right, and updated settings for
    droplit machine
    [Configuration.h]
2016-06-14 fixed ifs in ui
    [Configuration.h]
2016-06-15 Updated ERIS PID settings
    Updated ERIS PID Settings and endtop moves
    [Configuration.h]
2016-06-16 Updating PID's for eris
    PID update for eris
    [Configuration.h]
2016-06-21 fixed motor current configs and delta geometry
    fixed defines for motor current setting and delta geometry for diff.
    printers
    [Configuration.h]
2016-07-06 Updated PID values for original hotends with new PSU to help resistor burnout
    Updated PID values for original hotends with new PSU to help resistor
    burnout
    [Configuration.h]
2016-07-11 removed buggy comment in arduino 1.6.9
    Removed comment that was erroring out on arduino 1.6.9
    [Configuration.h]
2016-07-22 added define in coufniguration.h for inverting LCD encoder
    Added line in configuration.h to invert the encoder on the LCD
    controllers. Set to 0 or 1 to invert the direction of the knob
    [Configuration.h]
2016-07-26 fixed type
    fixed typo from comment posted by wmealing (thanks!)
    [Configuration.h]
2016-07-27 updated default printer/board for firmware
    made rostock and full rambo the default when first DL'd
    [Configuration.h]
2016-07-27 added homescreen infos
    added FW date to homescreen
    [Configuration.h]
2016-07-28 change motor current for rambo and encoder default direction
    change motor current for rambo and encoder default direction
    [Configuration.h]
2016-08-10 update PID and cooler fan settings
    Updated PID settings for current PEEK hotend and lowered fan pwm for
    cooler for new fan PN
    [Configuration.h]
2016-08-31 Added defines for new Rmax v3 and config updates for v3
    Added PRINTER = 5 for rmax v3 definitions and entered defaults. Changed
    probe pin for v3 to use rambo PS_ON pin for use with 2 pin latching
    connectors
    [Configuration.h]
2016-08-31 Added defines for rmaxv3 PID's and inverted motors for v3
    added PID defs for v3 and fixed motor direction defaults for v3
    [Configuration.h]
2016-09-08 updated config.h
    [Configuration.h]
2016-09-12 updated defines for probing and orion probe point
    Added define for probe pin to pull from board type not printer type and
    updated ORION probing positions
    [Configuration.h]
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2016-10-07 added page3 to show fw stuffs
    [Configuration.h]
2016-10-10 updating probe speeds so when pushed/merged
    merge will bring in probe speed updates per requests
    [Configuration.h]
2016-10-10 WIP on menus and defs
    [Configuration.h]
2016-10-10 updated probing speeds and default printer #
    [Configuration.h]
2016-10-10 updated z max for v3
    [Configuration.h]
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2016-10-11 config.h file cleanup and tweaks
    [Configuration.h]
2016-10-12 added comments to motor currents
    [Configuration.h]
2016-10-14 Added Power Supply define to config.h
    Added PSU define to config file for old/new style PSU's that drive the
    inverting of the Y axis motor. Newer PSU's in orions need the opposite
    inversion value of older orions
    [Configuration.h]
2016-10-28 updated configuration.h comments
    [Configuration.h]
2016-11-09 Variables instead of hardcoded several values
    [Configuration.h]
2016-11-11 Probing fixes
    [Configuration.h]
2016-11-14 Progressive Z Probe sensitivty decrease until successful probe values or until it hits 25
2016-11-14 Firmware date bump and mini-ramba variable fixed
    [Configuration.h]
2016-11-14 fixed defaults
    [Configuration.h]
2016-11-14 Z probe sensitivity tweaks
    [Configuration.h]
2016-11-14 Z probe errors logging tweak for octoprint compatability
2016-11-16 horizontal radius sanity check code added
    [Configuration.h]
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2016-11-17 defaut to Rostock v3
    [Configuration.h]
2016-11-17 date bump
    [Configuration.h]
2016-11-22 Logic fixed for inverted Y tower
    [Configuration.h]
2016-11-23 New Probe sequence (G29)
    [Configuration.h]
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2016-11-23 expanded probe sensitivity range
    [Configuration.h]
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2016-12-09 Horizontal Radius now checks a maximum of 4 times when calibrating w/ G29
    G30 double taps the bed at the current X/Y and reports PROBE-ZOFFSET: in the terminal with the +- height (mm) of the tap from Z0
    You can also specify an X and Y when calling 30 to move to the given XY before probing (ie: G30 X100 Y30)
    G30 will also decrease probe sensitivity if needed, but it is highly recommented to run G29 before running any G30s
    G30 S2 (which is called from the old calibrate scripts) will probe and set the Z height
    Configuration.h now has all the printer specific DEFINEs grouped together
    Printer Radius fixes
    [Configuration.h]
2016-12-09 fixed missing INVERT_Y_AXIS defines
    [Configuration.h]
2016-12-09 Added hex files for direct firmware flashing
    [Configuration.h]
2016-12-09 default config fix
    [Configuration.h]
2016-12-30 Added Hacker H2 Printer Fixes and tweaks to Configuration.h G30 probing array storage
    [Configuration.h]
2017-01-04 Turned off Ack w/ line number. Tweaked UI settings for H2
    [Configuration.h]
2017-01-09 Fixed Rostock V2 Y tower direction
    [Configuration.h]
2017-01-11 Fixed UI Max Temp
    [Configuration.h]
2017-01-20 Tweaked z probe offset
    [Configuration.h]
2017-02-01 Default Z Probe Height set to -0.1
    [Configuration.h]
2017-02-02 Updated hex files
    [Configuration.h]
2017-03-20 Streamlined Configuration.h and pins.h
    Dual Extrusion support (known tool change bug when printing over USB)
    Probe offset errors now displayed on LCD
    M84 can selectively disable steppers (by number)
    [Configuration.h]
2017-03-28 Configuration.h tweaks for easier setup
    [Configuration.h]
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2017-03-29 Oops Revert "printer pause change"
    This reverts commit ce454e34ebd6443f45102688ca0ea9297af0d11c.
2017-04-14 Pause from LCD fixed (no longer raises the print head) Rostock Max V2 w/ old hot end no longer gets accellerometer errors
    [Configuration.h]
2017-04-24 Removed CLONE variable
    [Configuration.h]
2017-05-15 Bugfix for old Orion w/ peek hotend
    [Configuration.h]
2017-07-27 Fixed Eris case fan issue and tweaked dual extrusion motor currents
    [Configuration.h]
2017-08-21 Removed 10 second pause before calibrating (if hot end > 100 degrees)
    [Configuration.h]
2017-08-22 Updated hex images
    [Configuration.h]
2017-10-26 Increased PID drive max for HE280
    [Configuration.h]
2017-10-30 G29 checks I2C connection before probing. Returns 'I2C Error' if connection is not solid and aborts probing
    [Configuration.h]
2017-11-15 Endstop error detection and logging - Can detect miswired/malfunctioning endstops I2C checks before probing - Does a double init before probing to make sure I2C connection is solid and aborts if it's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
    [Configuration.h]
2017-12-04 Added warning for Dual Extrusion bug
    [Configuration.h]
2017-12-04 fixed default NUM_EXTRUDER
    [Configuration.h]
2021-06-30 update settings
    [config.g, pause.g, trigger2.g]
2022-10-17 update v322 files
    [bed.g, config.g, pause.g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]
2022-11-22 update-files-versions
    A couple modifications. Mainly had a couple old version so the wifi bin file. So wiped and recopied all current productions files. WiFi bin file should be v1.27
    [bed.g, config.g, filaments.csv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]
2023-12-11 Create Restart Job Power Fail
2024-05-17 change note
    update notes to align with service bulletin for v3.4.4 firmware
    [config.g]
2024-11-04 updates
    match google drive values, correct boss 300 for under extruding due to config values for instantaneous speed changes and speeds etc ~partdaddy
    [LEGACY config.g, bed.g, config.g]
2024-11-24 update config values
    [40mmcubeCura462.3mf, Calibration 100mm SMC Deltas.3mf, Calibration 100mm SMC Deltas.STL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]
2025-04-04 add files
    Start of Orca support APRIL 2025 ~Steve
    [bed.g, cancel.g, config.g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]
2025-05-30 add v354 files
    starting point for Orca, but still works good with our Cura profiles
    [Calibration Square 30mm 07noz BOSS500 0521 Cura462.3mf, SeeMeCNC Cura45 QuickStart DUAL Test Wheel.3mf, SeeMeCNC Testing Wheel v4 DUAL Part A.stl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]
2025-07-13 config-g-m208
    set maximum M208 was previously not used, causing non-fatal error when homing
    [config.g]
2026-04-28 updates
    change line before G90 had wrong G1 Z-5 command - oops sorry
    [homedelta.g]
2026-05-06 add_362_configs
    replace 361 with new tested RRF 362 factory configs for RepRapFirmware 3.6.2+1.
    [SeeMeCNC Cura45 QuickStart DUAL Test Wheel.3mf, SeeMeCNC Testing Wheel v4 DUAL Part A.stl, SeeMeCNC Testing Wheel v4 DUAL Part B.stl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]
2026-05-20 update
    add v362+1 firmware and SMC machine configs and re-organize file structure and update to match files used in production.
    [40mmcubeCura462.3mf, Calibration 100mm SMC Deltas.3mf, Calibration 100mm SMC Deltas.STL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]
